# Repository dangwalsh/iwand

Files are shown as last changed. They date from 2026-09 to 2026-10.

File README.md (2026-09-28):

# iWand

iWand is a hand-held device that identifies the color of an object it's pointed at. Point it at something, press the button, and it announces the color out loud.

## Repo layout

- [`firmware/`](firmware/README.md) — embedded code for the Seeed XIAO ESP32S3, using a GY-33 color sensor and a DFPlayer Mini + speaker for audio announcement
- [`electrical/`](electrical/README.md) — KiCad project: schematic, routed 75.9 × 22 mm two-layer PCB, project footprint library (`iwand.pretty`), 3D models, and ready-to-order Gerbers (`fab/iwand-gerbers.zip`)
- [`mechanical/`](mechanical/README.md) — enclosure design in Onshape, with a STEP model of the populated PCB (`iwand-pcb.step`) exported from KiCad

Each directory's README has setup/dependency details specific to that part of the project; `firmware/CLAUDE.md` has the full architecture writeup (wake/sleep flow, pin assignments, library APIs).

## Status

- **Firmware:** a single-file sketch. It runs on hardware with calibration and spoken prompts. The battery-voltage monitor (D10) isn't read yet.
- **Electrical:** the PCB is routed and passes KiCad's design rules and schematic parity checks, with Gerbers ready to order. It hasn't been built or tested yet.
- **Mechanical:** enclosure design in Onshape has just started, from the exported PCB model. The layout along the wand, the component sizes and the required openings are in `mechanical/README.md`.

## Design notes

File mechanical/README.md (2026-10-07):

# iWand — Mechanical

iWand is a hand-held device that identifies the color of an object it's pointed at. This directory holds the mechanical/enclosure design; sibling directories at the repo root hold the corresponding work for the same product — `firmware/` (embedded code) and `electrical/` (KiCad schematic, `iwand.kicad_pro`/`.kicad_sch`, title block "iWand").

The enclosure is designed in Onshape. This directory holds:

- `iwand-pcb.step`: a STEP model of the populated PCB exported from KiCad, which is the reference the enclosure is built around.
- `iWand - Enclosure Top.step`, `iWand - Enclosure Middle.step`, `iWand - Enclosure Rear.step`: the three parts of the enclosure, exported from Onshape. The Onshape document is the source of truth, so re-export these files after design changes.

## Dependencies

- **Onshape** (browser-based) for the enclosure design.
- **KiCad 10** (`kicad-cli`) to re-export `iwand-pcb.step` after the board changes.

## PCB model

`iwand-pcb.step` is the board plus every part that has a 3D model, in millimetres. To re-export it after changing `electrical/iwand.kicad_pcb`, run this from the repo root:

```
"C:\Program Files\KiCad\10.0\bin\kicad-cli.exe" pcb export step --subst-models --force -o mechanical/iwand-pcb.step electrical/iwand.kicad_pcb
```

The XIAO and DFPlayer models come from `electrical/3dmodels/`, and the rest come from KiCad's standard library.

To use it in Onshape, import the file (Import, or drag it onto the Documents page), then insert the resulting Part Studio into an Assembly with the enclosure. After a re-export, use "Update" on the imported part to pick up the new version.

The model leaves out:

- **Q1/Q2:** the `AO3400_SOT23_Adapter` footprint has no 3D model. Allow about 7.6 x 10 mm lying flat on their pins.
- **All off-board parts:** the GY-33, speaker, SW1, LiPo and the JST plugs and cables. Model these in Onshape from the sizes below.

## Components to accommodate

Per the electrical schematic (source of truth: `electrical/iwand.kicad_sch`):

On the main PCB:

- **U1:** Seeed XIAO ESP32S3 (MCU), 21 x 17.8 mm, in female header sockets. Its USB-C port must stay reachable for charging and flashing.
- **U3:** DFPlayer Mini (audio playback), 20.3 x 20.3 mm, in female header sockets. Its microSD slot opens toward the front of the wand, right beside J1, so there's no finger room to swap the card in place. Pull the DFPlayer out of its sockets to change the audio files.
- **Q1/Q2:** AO3400 MOSFETs on SOT-23 adapter boards (~7.6 x 10 mm), mounted flat on their pins. **R1–R4:** through-hole resistors, mounted upright.
- **J1–J4:** JST-PH side-entry sockets, which need room for the plugs and cable bends.
- **SW2:** a right-angle slide switch (power). Its lever sticks out about 4 mm past the same long edge as the USB-C, about 13 mm forward of it, so one side opening or two small cut-outs can serve both.

The board is 75.9 x 22 mm. Its tallest point is the top of the XIAO, about 10–11 mm above the board (3.8 mm low-profile socket + 2.5 mm pin spacer + the module). Pin tails stick out up to about 3 mm below. The XIAO's USB-C port sits over one long edge of the board and must line up with a slot in the enclosure wall.

**Charging:** the battery stays in and charges over USB-C, but only with SW2 switched on. The XIAO's small charge LED sits on top of the module, right beside the USB-C port. Leave a window or light pipe above it, or make the USB slot wide enough to show the glow.

Off-board, on JST-PH cables:

- **GY-33 color sensor (J1):** 24.3 x 26.7 mm, with four corner screw holes about 21 x 19.7 mm apart (measured from a photo, to be confirmed with calipers). The sensor and LEDs face forward, so it needs an aperture at the pointing end of the wand. Allow about 20 mm behind it for the cable.
- **Speaker (J2):** 8 Ω, 28 mm round, ~5 mm deep. It needs a grille, ideally with a closed back volume.
- **Wake button SW1 (J3):** a panel-mount momentary pushbutton, reachable as the wand's trigger.
- **LiPo (J4):** 3.7 V, with a compartment. It stays connected and charges in place, so it only needs access for replacement.

The widest parts are the speaker (28 mm) and the GY-33's face, which together set the enclosure's minimum cross-section.

## Layout along the wand

From rear to front: **speaker (rear end cap) → battery → PCB → GY-33 (tip)**.

- The battery, speaker and button plugs (J4, J2, J3) face the rear, toward the battery and speaker, which keeps their leads short. The plug housings stick out about 7 mm behind the board, so leave that gap, plus room for the cables to bend, before the battery.
- The battery sits on the wand's centre line, so the weight stays centred. Any cell that fits the tube's inside diameter will do. It doesn't need to fit under the board.
- J1 faces forward. The GY-33 cable runs from it to the sensor at the tip, and needs about 20 mm behind the sensor.

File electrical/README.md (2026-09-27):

# iWand Electrical

KiCad schematic for the iWand color-identifying wand (Seeed XIAO ESP32S3 + GY-33 color sensor + DFPlayer Mini + AO3400 power gating). See `firmware/CLAUDE.md` for how the pin assignments here map to the firmware.

## Dependencies

- **KiCad 7.0 or newer** (developed with KiCad 10). The schematic (`iwand.kicad_sch`) is in the KiCad 7 s-expression format (`version 20230121`). Older KiCad versions won't open it.

The module symbols (`wand_parts:XIAO_ESP32S3`, `wand_parts:DFPlayer_Mini`) are embedded directly in `iwand.kicad_sch`, so there's no external symbol library to install. ERC warns that the `wand_parts` library isn't configured and that `Device:Q_NMOS_GDS` is missing from KiCad's current `Device` library. Both warnings are harmless, because the embedded copies are used.

## Footprints

Project footprints live in `iwand.pretty`, registered through the project's `fp-lib-table` as `iwand`:

| Footprint | Used by | Source |
|---|---|---|
| `XIAO_ESP32S3_Socket` | U1 | Pad positions from Seeed's `XIAO-ESP32-S3-DIP`, without its castellated SMD pads. USB-C is at +X; B+/B- on the fab layer mark the underside battery pads. |
| `DFPlayer_Mini_Socket` | U3 | DFR0299 datasheet drawing: 20.32 mm square, 2 x 8 pins, rows 18.034 mm apart. |
| `AO3400_SOT23_Adapter` | Q1, Q2 | 1 x 3 pins in the adapter board's S-D-G order (adapter labels 2-3-1). Pads are numbered for `Q_NMOS_GDS`. The adapter outline (~7.6 x 10 mm) is estimated from a photo. |

Everything else is stock KiCad:
- DIN0207 through-hole resistors, lying flat
- a 3 mm disc capacitor
- a C&K OS102011MA1QN1-style right-angle slide switch
- JST-PH side-entry sockets (J1-J4)
- a 1 x 2 pin header (J5)

## Board

The board is 75.9 x 22 mm, laid out as a "spine" along the wand. From the rear:
- J4 battery, J2 speaker and J3 button plugs, facing the rear
- the XIAO, with USB-C over the lower long edge; R1-R6 lie flat underneath it
- Q1/Q2 with J5, SW2 and C1
- the DFPlayer
- J1, facing forward to the GY-33

The module sockets are 3M 929870 low-profile strips, 3.8 mm tall, bought as 10-pin strips and cut to length. In them, the XIAO sits about 6.3 mm up (3.8 mm socket + 2.5 mm pin spacer). Its courtyard therefore covers only its socket strips and USB plug, so parts up to about 5 mm tall can go underneath.

For the 3D view:
- **Sockets:** 3M's STEP model is a 10-pin strip, so the view uses KiCad's 1x7/1x8 socket models scaled to 3.8 mm instead.
- **XIAO:** Seeed's STEP file (in `3dmodels/`), drawn 6.3 mm up. The pin spacer under it isn't modelled.
- **DFPlayer:** DFRobot's DFR0299 STEP file (in `3dmodels/`, drawn in inches, Y-up). It includes the module's own pin header, with its spacer resting on the socket top. Its microSD slot opens toward the front of the board, facing J1.

Do a dry fit before soldering. A standard 6 mm male pin may bottom out in a 3.8 mm socket and ride slightly higher than 6.3 mm.

## Mounting and off-board parts

- U1 and U3 plug into female header sockets so they stay removable. Q1/Q2 are AO3400s already soldered to SOT-23 adapter boards, which are mounted flat on their pins.
- The GY-33, speaker, wake button and battery sit off the board on JST-PH connectors:
  - **J1 (GY-33):** a 4-wire pigtail soldered into the sensor's GND/DR/CT/VCC holes, in that order.
  - **J2:** speaker.
  - **J3:** wake button.
  - **J4:** LiPo.
- JST battery polarity isn't standardised. Check each battery against the board's + mark before plugging it in.
- The XIAO's battery pads are on its underside, not on its headers. **J5** takes two short wires from those BAT+/BAT- pads so the XIAO can run from, and charge, the battery on J4.

## Power and charging

- The battery stays in the wand and charges through the XIAO's USB-C (about 100 mA).
- **SW2** is the power switch, in the battery + lead (J4 → SW2 → VBAT). Off disconnects everything, including the charger, so the battery only charges with SW2 on.
- The XIAO's charge LED sits next to its USB-C port, so the enclosure needs a window or light pipe there.
- **R5/R6** (1M each) divide VBAT by 2 into D10, which is an ADC input. **C1** (100 nF) steadies the reading. The divider draws about 2 µA, and nothing when SW2 is off.

## Routing and fabrication

- **Stack-up:** 2 layers, 1.6 mm. Rules: 0.2 mm clearance, 0.5 mm copper to edge. Every connection is routed. DRC and the schematic parity check pass with no errors.
- **Net classes:**
  - **Default:** 0.25 mm tracks, 0.6/0.3 mm vias.
  - **Power:** 0.5 mm tracks, 0.8/0.4 mm vias. Covers `VBAT`, `BAT_IN`, `GND`, `SPK1`/`SPK2`, `AUDIO_GND` and `SENSOR_GND`. Branches to R5/R6/C1 and the gate resistors use 0.25 mm, since they carry almost no current.
- **Module socket pads:** 1.6 mm, so a 0.25 mm track can pass between two 2.54 mm-pitch pins.
- **Ground:** GND pours on both layers, tied together by stitching vias.
- **Fab files:** `fab/iwand-gerbers.zip` (copper, mask, silkscreen, edge cuts, and plated and non-plated drill files). Regenerate it with KiCad's Fabrication Outputs, or with `kicad-cli pcb export gerbers` / `export drill`, after any board change.

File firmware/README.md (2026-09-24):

# iWand Firmware

Firmware for the iWand color-identifying wand (Seeed XIAO ESP32S3 + GY-33 color sensor + DFPlayer Mini). See `CLAUDE.md` for architecture and pin assignment details.

## Dependencies

Install via the Arduino IDE Library Manager:

- **GY33_Colour_Sensor** — driver for the GY-33 color sensor (TCS34725-based), used over I2C. Source: https://github.com/You-010/GY33_Arduino
- **DFRobotDFPlayerMini** — driver for the DFPlayer Mini MP3 module, used over UART. Source: https://github.com/DFRobot/DFRobotDFPlayerMini

Board support: install the **esp32** board package (Espressif Systems) via Boards Manager, and select an ESP32S3 board profile (e.g. "XIAO_ESP32S3" if available, otherwise a generic "ESP32S3 Dev Module").

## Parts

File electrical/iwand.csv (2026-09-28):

Reference | Qty | Value | DNP | Exclude from BOM | Exclude from Board | Exclude from Simulation | Exclude from Position Files | Footprint | Datasheet
C1 | 1 | 100n |  |  |  |  | ${EXCLUDE_FROM_POS_FILES} | Capacitor_THT:C_Disc_D3.0mm_W1.6mm_P2.50mm
J1 | 1 | GY-33 (GND DR CT VCC) |  |  |  |  | ${EXCLUDE_FROM_POS_FILES} | Connector_JST:JST_PH_S4B-PH-K_1x04_P2.00mm_Horizontal
J2 | 1 | Speaker 8R |  |  |  |  | ${EXCLUDE_FROM_POS_FILES} | Connector_JST:JST_PH_S2B-PH-K_1x02_P2.00mm_Horizontal
J3 | 1 | Wake button SW1 |  |  |  |  | ${EXCLUDE_FROM_POS_FILES} | Connector_JST:JST_PH_S2B-PH-K_1x02_P2.00mm_Horizontal
J4 | 1 | LiPo 3.7V (+ -) |  |  |  |  | ${EXCLUDE_FROM_POS_FILES} | Connector_JST:JST_PH_S2B-PH-K_1x02_P2.00mm_Horizontal
J5 | 1 | XIAO BAT+ BAT- link |  |  |  |  | ${EXCLUDE_FROM_POS_FILES} | Connector_PinHeader_2.54mm:PinHeader_1x02_P2.54mm_Vertical
Q1,Q2 | 2 | AO3400 |  |  |  |  | ${EXCLUDE_FROM_POS_FILES} | iwand:AO3400_SOT23_Adapter
R1,R3 | 2 | 100 |  |  |  |  | ${EXCLUDE_FROM_POS_FILES} | Resistor_THT:R_Axial_DIN0207_L6.3mm_D2.5mm_P7.62mm_Horizontal
R2,R4 | 2 | 10k |  |  |  |  | ${EXCLUDE_FROM_POS_FILES} | Resistor_THT:R_Axial_DIN0207_L6.3mm_D2.5mm_P7.62mm_Horizontal
R5,R6 | 2 | 1M |  |  |  |  | ${EXCLUDE_FROM_POS_FILES} | Resistor_THT:R_Axial_DIN0207_L6.3mm_D2.5mm_P7.62mm_Horizontal
SW2 | 1 | Power |  |  |  |  | ${EXCLUDE_FROM_POS_FILES} | Button_Switch_THT:SW_Slide_SPDT_Angled_CK_OS102011MA1Q
U1 | 1 | XIAO ESP32-S3 |  |  |  |  | ${EXCLUDE_FROM_POS_FILES} | iwand:XIAO_ESP32S3_Socket
U3 | 1 | DFPlayer Mini |  |  |  |  | ${EXCLUDE_FROM_POS_FILES} | iwand:DFPlayer_Mini_Socket

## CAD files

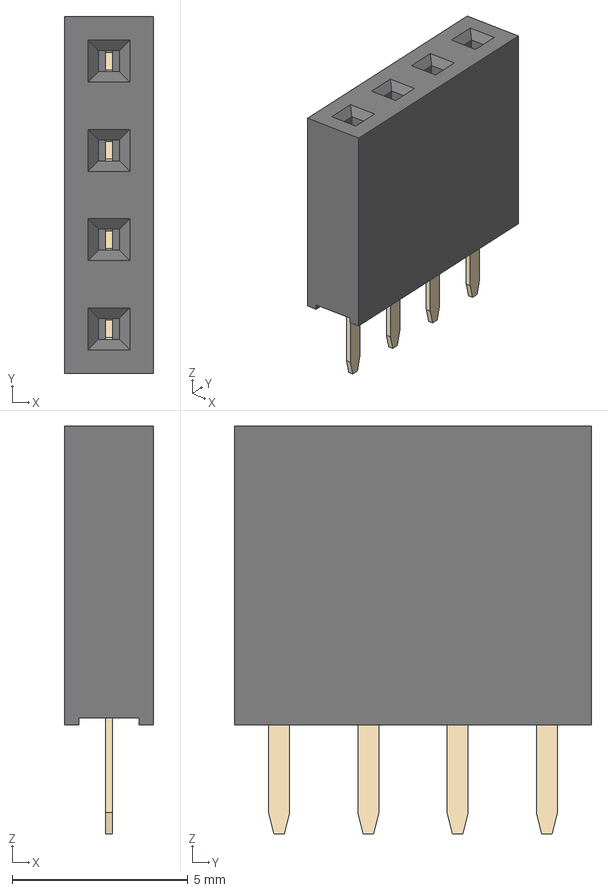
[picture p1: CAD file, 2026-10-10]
electrical/3dmodels/PinSocket_1x04_P2.54mm_Vertical.step
2.54 x 10.2 x 11.6 mm

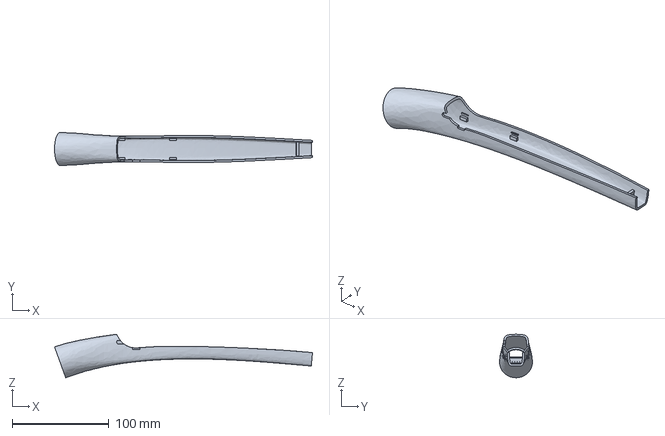
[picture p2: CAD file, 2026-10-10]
mechanical/iWand - Enclosure Middle.step
267.0 x 34.0 x 45.1 mm

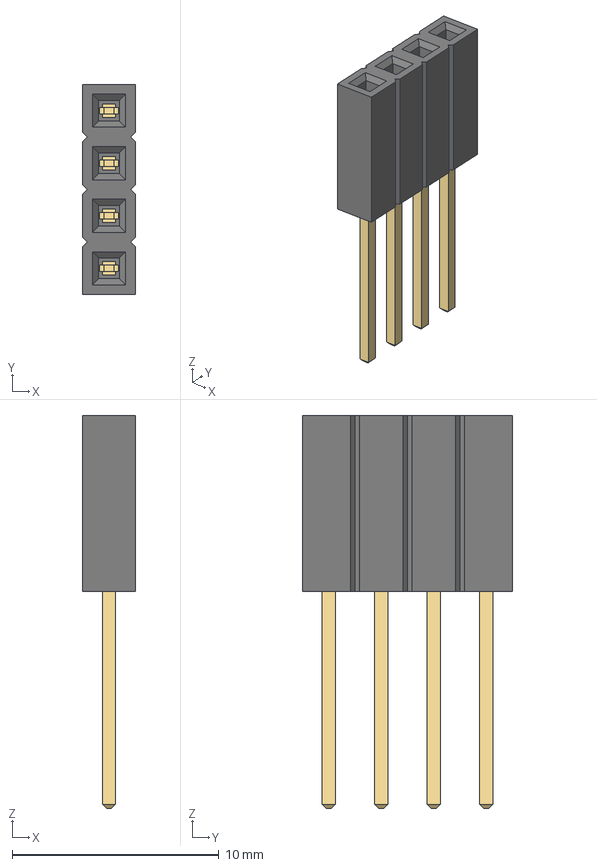
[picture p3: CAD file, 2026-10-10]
electrical/3dmodels/PinSocket_1x04_P2.54mm_Vertical_Stacking.step
2.54 x 10.2 x 19.0 mm
pins

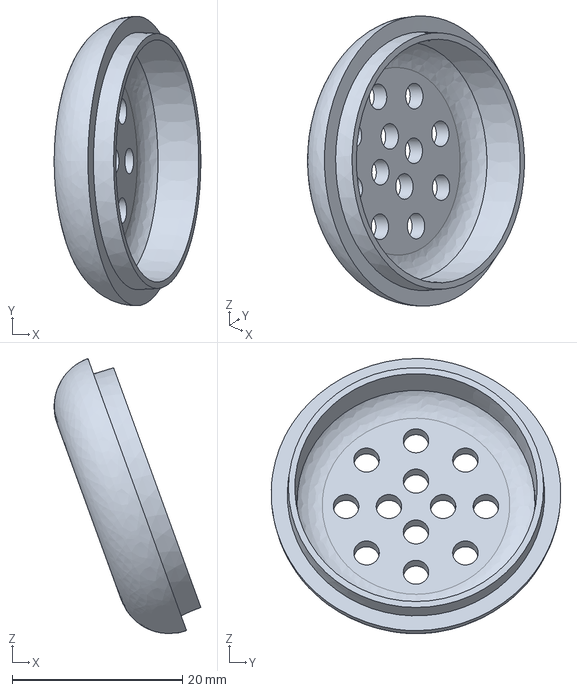
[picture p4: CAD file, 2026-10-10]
mechanical/iWand - Enclosure Rear.step
17.3 x 34.0 x 32.3 mm

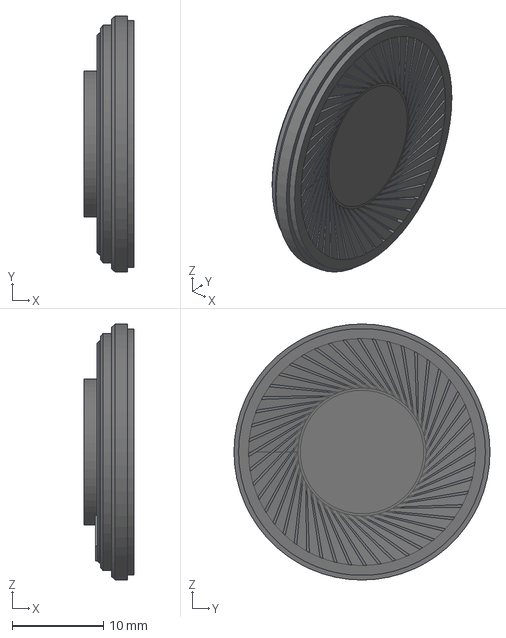
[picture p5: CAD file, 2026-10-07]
electrical/3dmodels/28mm 2W 8 Ohm Speaker.step
5.50 x 28.0 x 28.0 mm

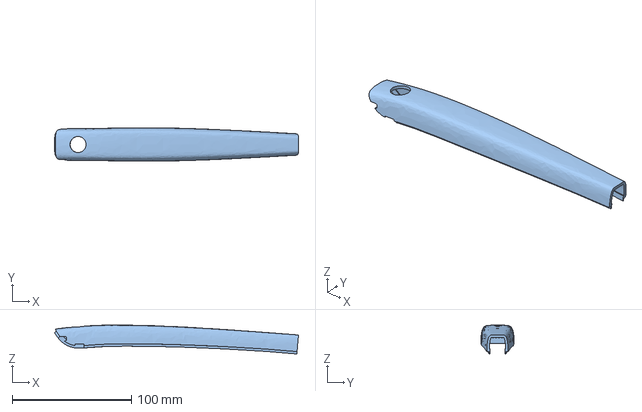
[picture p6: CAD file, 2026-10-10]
mechanical/iWand - Enclosure Top.step
204.6 x 28.1 x 24.3 mm

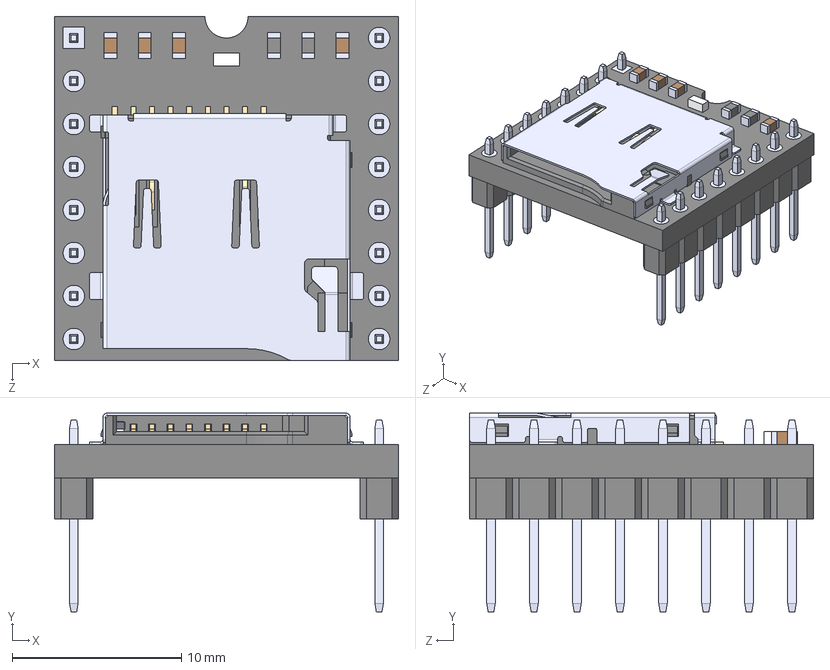
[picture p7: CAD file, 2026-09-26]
electrical/3dmodels/DFPlayer_Mini.step
20.3 x 11.8 x 20.3 mm

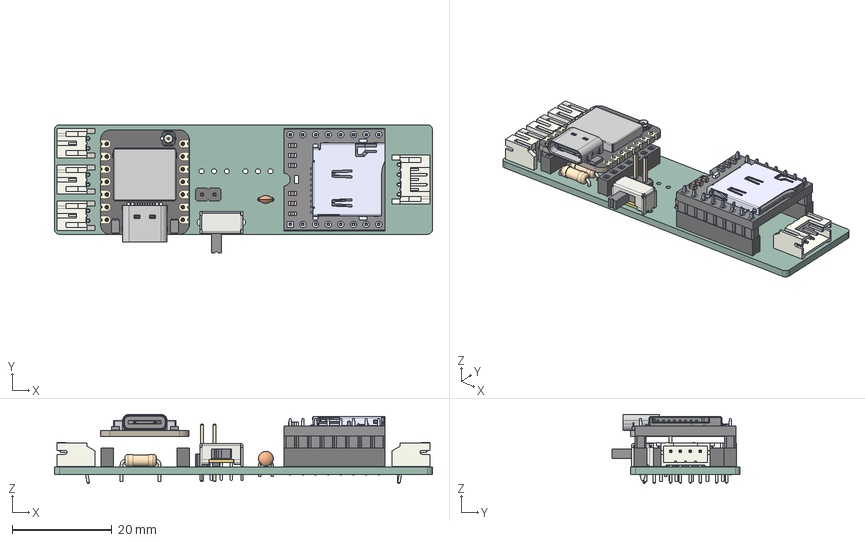
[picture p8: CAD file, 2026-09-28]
mechanical/iwand-pcb.step
75.9 x 25.8 x 13.9 mm
JST_S2B_PH_K x 3
R_Axial_DIN0207_L63mm_D25mm_P762mm_Horizontal x 6
SW_Slide_SPDT_Angled_CK_OS102011MA1Q
JST_S4B_PH_K
PinSocket_1x08_P2.54mm_Vertical x 2
DFR0299
PinHeader_1x02_P254mm_Vertical
C_Disc_D30mm_W16mm_P250mm
PinSocket_1x07_P2.54mm_Vertical x 2
BOSS-EXTRUDE14_8_
BOSS-EXTRUDE7_4_
BOSS-EXTRUDE7_3_
BOSS-EXTRUDE14_4_
BOSS-EXTRUDE14_2_
BOSS-EXTRUDE14_11_
BOSS-EXTRUDE7_7_
BOSS-EXTRUDE14_9_
BOSS-EXTRUDE14_3_
BOSS-EXTRUDE14_7_
MIRROR2
BOSS-EXTRUDE14_5_
BOSS-EXTRUDE14_12_
BOSS-EXTRUDE7_8_
BOSS-EXTRUDE7_1_
BOSS-EXTRUDE14_10_
BOSS-EXTRUDE7_9_
BOSS-EXTRUDE14_6_
BOSS-EXTRUDE14_1_
BOSS-EXTRUDE7_6_
BOSS-EXTRUDE7_2_
CUT-EXTRUDE5
BOSS-EXTRUDE7_5_
Shield
Pins x 2
U.FL-R-SMT-1_10_ v1
iwand_PCB

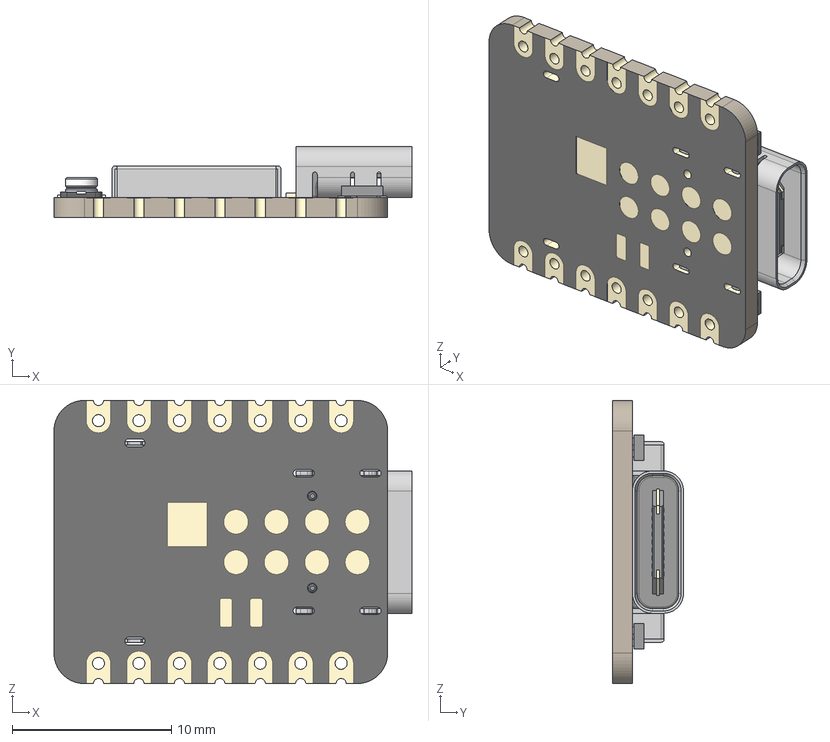
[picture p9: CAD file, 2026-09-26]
electrical/3dmodels/XIAO-ESP32S3.step
22.5 x 4.46 x 17.8 mm
BOSS-EXTRUDE14_8_
BOSS-EXTRUDE7_4_
BOSS-EXTRUDE7_3_
BOSS-EXTRUDE14_4_
BOSS-EXTRUDE14_2_
BOSS-EXTRUDE14_11_
BOSS-EXTRUDE7_7_
BOSS-EXTRUDE14_9_
BOSS-EXTRUDE14_3_
BOSS-EXTRUDE14_7_
MIRROR2
BOSS-EXTRUDE14_5_
BOSS-EXTRUDE14_12_
BOSS-EXTRUDE7_8_
BOSS-EXTRUDE7_1_
BOSS-EXTRUDE14_10_
BOSS-EXTRUDE7_9_
BOSS-EXTRUDE14_6_
BOSS-EXTRUDE14_1_
BOSS-EXTRUDE7_6_
BOSS-EXTRUDE7_2_
CUT-EXTRUDE5
BOSS-EXTRUDE7_5_
Shield
Pins x 2
U.FL-R-SMT-1_10_ v1

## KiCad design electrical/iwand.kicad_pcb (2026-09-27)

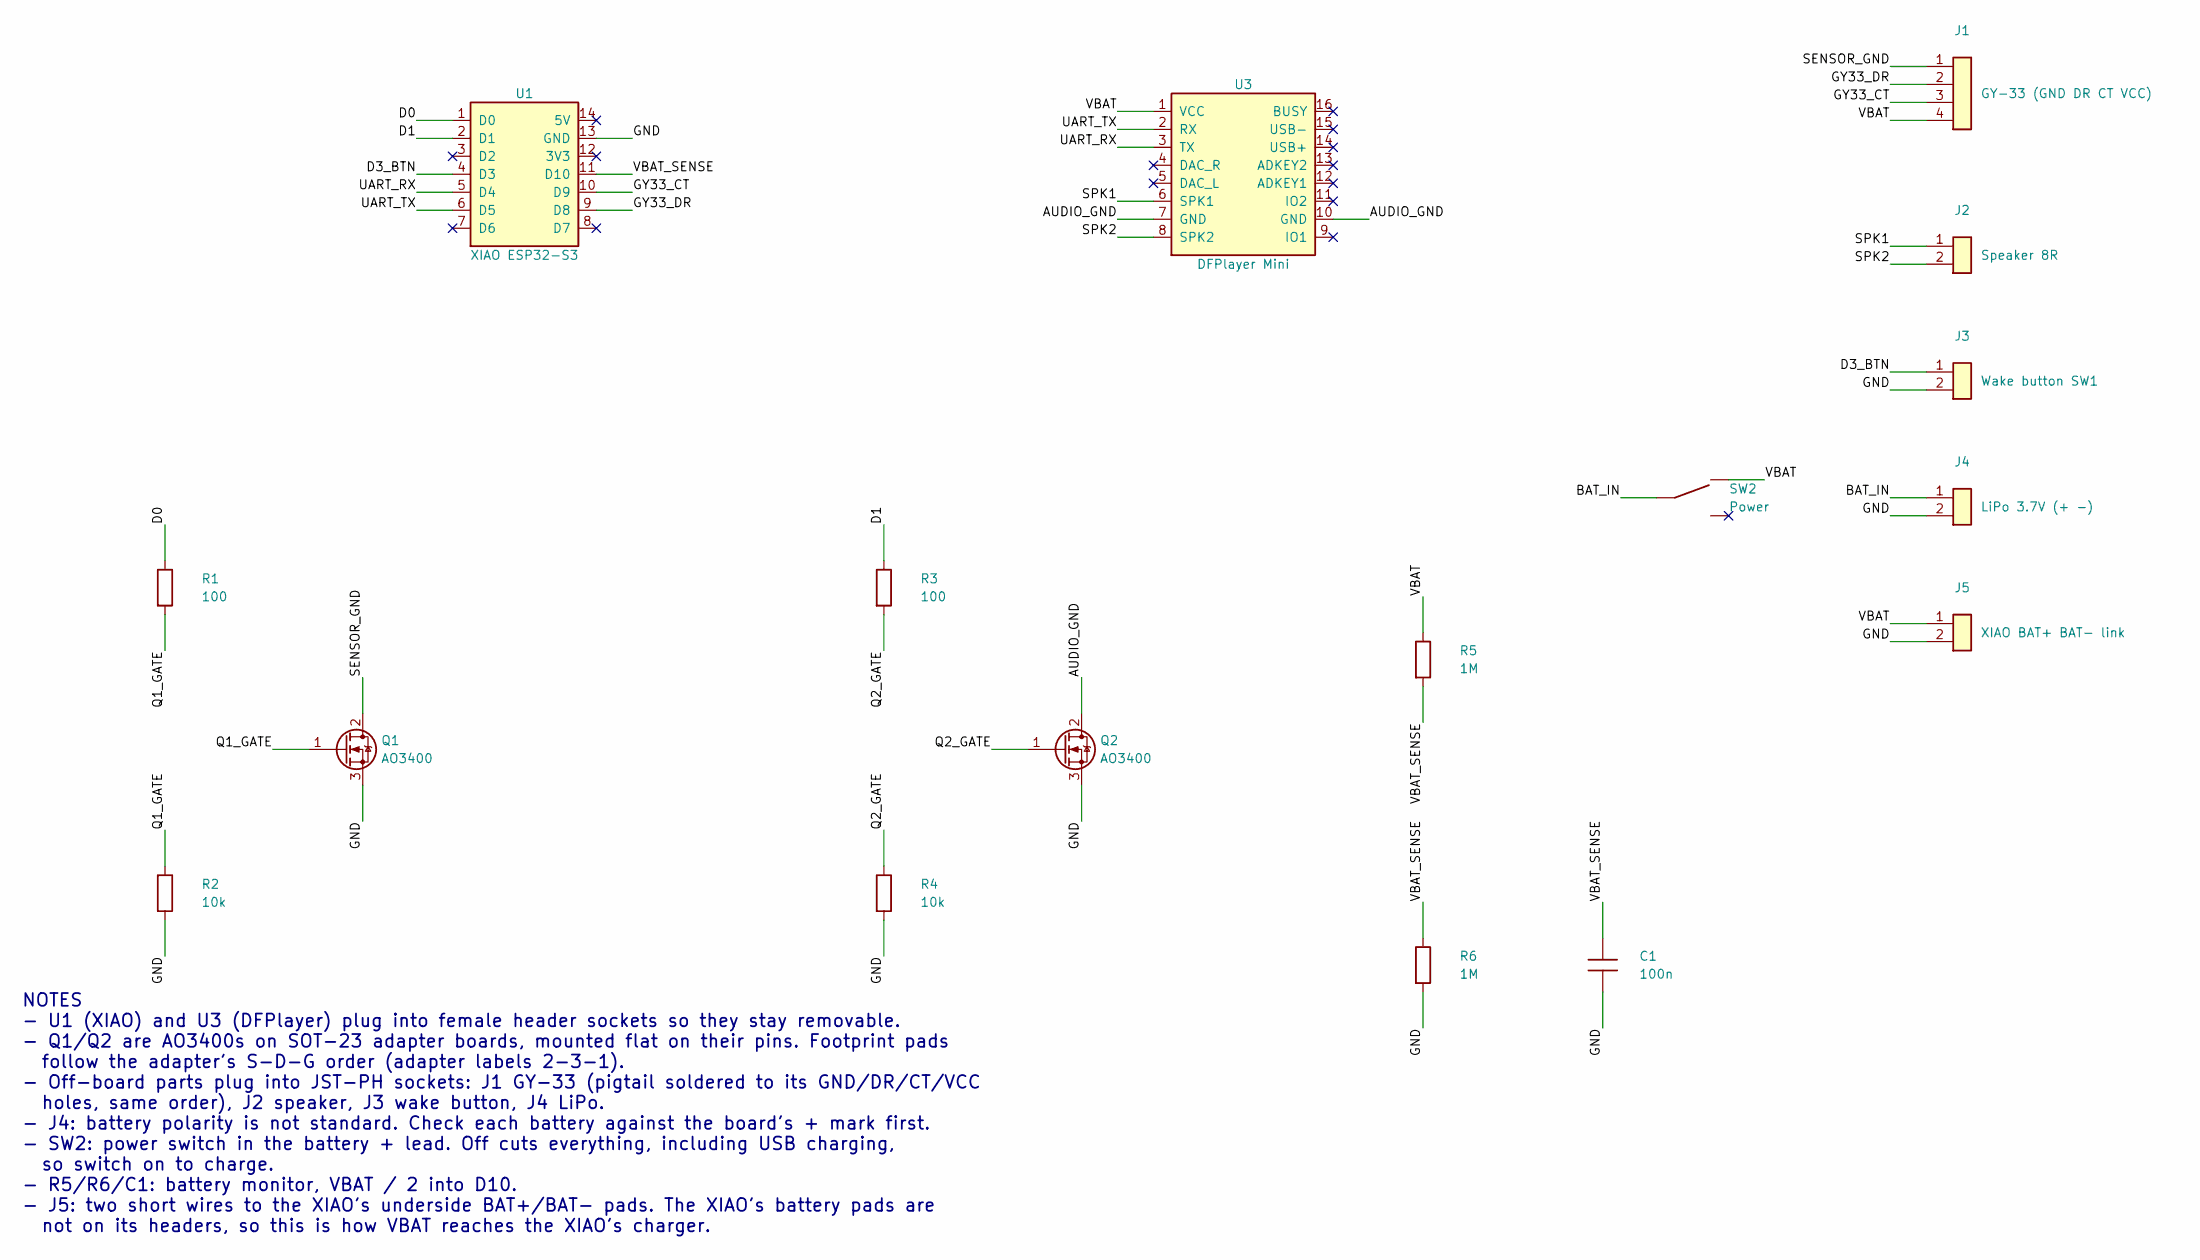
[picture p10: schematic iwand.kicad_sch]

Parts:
C1: 100n; C_Disc_D3.0mm_W1.6mm_P2.50mm
J1: GY-33 (GND DR CT VCC); JST_PH_S4B-PH-K_1x04_P2.00mm_Horizontal
J2: Speaker 8R; JST_PH_S2B-PH-K_1x02_P2.00mm_Horizontal
J3: Wake button SW1; JST_PH_S2B-PH-K_1x02_P2.00mm_Horizontal
J4: LiPo 3.7V (+ -); JST_PH_S2B-PH-K_1x02_P2.00mm_Horizontal
J5: XIAO BAT+ BAT- link; PinHeader_1x02_P2.54mm_Vertical
Q1, Q2: AO3400; AO3400_SOT23_Adapter
R1, R3: 100; R_Axial_DIN0207_L6.3mm_D2.5mm_P7.62mm_Horizontal
R2, R4: 10k; R_Axial_DIN0207_L6.3mm_D2.5mm_P7.62mm_Horizontal
R5, R6: 1M; R_Axial_DIN0207_L6.3mm_D2.5mm_P7.62mm_Horizontal
SW2: Power; SW_Slide_SPDT_Angled_CK_OS102011MA1Q
U1: XIAO ESP32-S3; XIAO_ESP32S3_Socket
U3: DFPlayer Mini; DFPlayer_Mini_Socket

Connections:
/AUDIO_GND: Q2.2 (D), U3.7 (GND), U3.10 (GND)
/BAT_IN: J4.1, SW2.2 (B)
/D0: R1.1, U1.1 (D0)
/D1: R3.1, U1.2 (D1)
/D3_BTN: J3.1, U1.4 (D3)
/GND: C1.2, J3.2, J4.2, J5.2, Q1.3 (S), Q2.3 (S), R2.2, R4.2, R6.2, U1.13 (GND)
/GY33_CT: J1.3, U1.10 (D9)
/GY33_DR: J1.2, U1.9 (D8)
/Q1_GATE: Q1.1 (G), R1.2, R2.1
/Q2_GATE: Q2.1 (G), R3.2, R4.1
/SENSOR_GND: J1.1, Q1.2 (D)
/SPK1: J2.1, U3.6 (SPK1)
/SPK2: J2.2, U3.8 (SPK2)
/UART_RX: U1.5 (D4), U3.3 (TX)
/UART_TX: U1.6 (D5), U3.2 (RX)
/VBAT: J1.4, J5.1, R5.1, SW2.1 (A), U3.1 (VCC)
/VBAT_SENSE: C1.1, R5.2, R6.1, U1.11 (D10)

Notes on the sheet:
NOTES - U1 (XIAO) and U3 (DFPlayer) plug into female header sockets so they stay removable. - Q1/Q2 are AO3400s on SOT-23 adapter boards, mounted flat on their pins. Footprint pads follow the adapter's S-D-G order (adapter labels 2-3-1). - Off-board parts plug into JST-PH sockets: J1 GY-33 (pigtail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

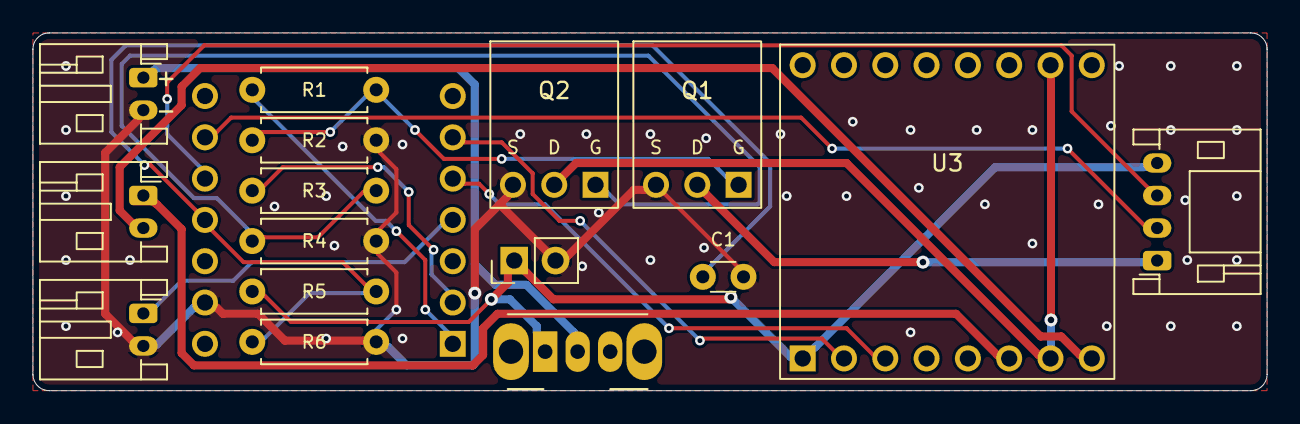
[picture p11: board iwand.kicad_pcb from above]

Board: 2 copper layers, 75.9 x 22.0 mm, 17 parts (0 on the bottom side), 17 nets.

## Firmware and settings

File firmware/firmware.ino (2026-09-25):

#include <Wire.h>                  // not used directly; GY33.h depends on it
#include <GY33.h>                  // https://github.com/You-010/GY33_Arduino
#include <DFRobotDFPlayerMini.h>   // DFRobot DFPlayer Mini MP3 module
#include <esp_sleep.h>
#include <driver/rtc_io.h>         // RTC-domain pull-up for the wake pin during deep sleep
#include <Preferences.h>           // ESP32 NVS -- persists the black offset across deep sleep

// ---------------------------------------------------------------------------
// Pin assignments -- from the schematic, board is a Seeed XIAO ESP32S3.
// Silkscreen D-labels translated to GPIO numbers per Seeed's pinout:
//   D0=GPIO1  D1=GPIO2  D3=GPIO4  D4=GPIO5  D5=GPIO6  D8=GPIO7  D9=GPIO8
// Sensor MOSFET gate moved from D2 (GPIO3, an ESP32-S3 strapping pin) to
// D0 (GPIO1), a plain unused pin with no competing native function -- update
// the schematic's R1 net from D2 to D0 to match.
// D4/D5 UART roles match the schematic's crossover wiring (D4 = MCU RX, fed
// by DFPlayer TX; D5 = MCU TX, feeding DFPlayer RX).
// D8/D9 are wired to the GY-33's DR/CT pins, which are SDA/SCL in I2C mode
// and RX/TX in serial mode. The sensor runs in serial mode (its factory
// default), so D8 = MCU TX -> GY-33 DR (RX), D9 = MCU RX <- GY-33 CT (TX).
// Grouped for tidiness: D0/D1 = MOSFET gates, D3 = wake button, D4/D5 =
// DFPlayer UART, D8/D9 = GY-33 UART.
// ---------------------------------------------------------------------------
#define SENSOR_MOSFET_PIN  1   // D0: R1 -> Q1 gate, switches GY-33 power
#define PLAYER_MOSFET_PIN  2   // D1: R3 -> Q2 gate, switches DFPlayer power
#define WAKE_BUTTON_PIN    4   // D3: SW1 to GND; wakes MCU via ext0 (active LOW)
#define DFPLAYER_RX_PIN    5   // D4: ESP32 RX <- DFPlayer TXD
#define DFPLAYER_TX_PIN    6   // D5: ESP32 TX -> DFPlayer RXD
#define SENSOR_TX_PIN      7   // D8: ESP32 TX -> GY-33 DR (RX)
#define SENSOR_RX_PIN      8   // D9: ESP32 RX <- GY-33 CT (TX)

// Assumes each AO3400 is wired as a low-side switch (drain to the device's
// ground return, source to system ground): gate HIGH turns the device ON.
// Invert these if the hardware ends up wired the other way.
#define MOSFET_ON  HIGH
#define MOSFET_OFF LOW

#define SENSOR_WARMUP_MS  300   // GY-33 settle time after power-up -- untested guess, tune later
#define SENSOR_BAUD       9600  // GY-33 factory-default serial baud rate
#define PLAYER_WARMUP_MS  2000  // DFPlayer Mini needs time to mount its SD card before it'll respond
#define PLAYER_VOLUME     20    // 0-30
#define READ_TIMEOUT_MS   1000
// In serial mode the GY-33 streams one frame per output type (raw, LCC,
// processed -- all enabled by begin()) and update() returns true for each.
// Waiting for this many frames ensures every field has fresh data.
#define FRAMES_PER_READING 3
// Colour classification thresholds, on channels normalised so the calibrated
// black point is 0 and the white point is 1, then gamma-encoded to match how
// bright things look (see classifyColour()) -- tune on real targets using the
// "Normalised" debug line.
#define DISPLAY_GAMMA        2.2f   // standard sRGB-like perceptual curve
#define BLACK_MAX_VALUE      0.25f  // brightest channel below this -> Black
#define WHITE_MIN_VALUE      0.80f  // unsaturated and at least this bright -> White, else Gray
#define WHITE_MAX_SATURATION 0.15f  // channels this close together -> White/Gray/Black
#define PLAY_TIMEOUT_MS   5000
// Spoken calibration prompts, in the SD card's /mp3 folder.
#define TRACK_CAL_WHITE   11    // 0011.mp3: "point at white and press the button"
#define TRACK_CAL_BLACK   12    // 0012.mp3: "point at black and press the button"
#define TRACK_CAL_DONE    13    // 0013.mp3: "calibration complete"
#define CAL_STEP_TIMEOUT_MS 30000 // abort calibration if SW1 isn't pressed in time, to save battery
#define CAL_SETTLE_MS     500     // time for the GY-33 to finish white balance -- untested guess
#define DEBOUNCE_MS       30
// Debug aid: the XIAO's USB serial drops during deep sleep and the host takes
// a moment to reconnect after each wake, so early prints are lost. Wait up to
// this long for the serial monitor at boot. Set to 0 for battery use.
#define SERIAL_WAIT_MS    3000

HardwareSerial sensorSerial(2);
GY33_UART sensor(sensorSerial);
HardwareSerial dfSerial(1);
DFRobotDFPlayerMini player;
bool playerReady = false;
Preferences prefs;

// Raw reading of the white calibration target, loaded from NVS at boot.
GY33_Raw whitePoint = {0, 0, 0, 0};
bool haveWhitePoint = false;

// Maps a classifyColour() name to a track number on the DFPlayer's SD card.
// Track files live in the card's /mp3 folder as 0001.mp3, 0002.mp3, etc.
// (see playTrack()).
int trackForColour(const char* colour) {
  if (strcmp(colour, "Black") == 0)  return 1;
  if (strcmp(colour, "White") == 0)  return 2;
  if (strcmp(colour, "Gray") == 0)   return 3;
  if (strcmp(colour, "Red") == 0)    return 4;
  if (strcmp(colour, "Orange") == 0) return 5;
  if (strcmp(colour, "Yellow") == 0) return 6;
  if (strcmp(colour, "Green") == 0)  return 7;
  if (strcmp(colour, "Cyan") == 0)   return 8;
  if (strcmp(colour, "Blue") == 0)   return 9;
  if (strcmp(colour, "Purple") == 0) return 10;
  return 0; // unrecognised -- don't play anything
}

void powerSensorOn() {
  digitalWrite(SENSOR_MOSFET_PIN, MOSFET_ON);
  delay(SENSOR_WARMUP_MS);
}

void powerSensorOff() {
  digitalWrite(SENSOR_MOSFET_PIN, MOSFET_OFF);
}

void powerPlayerOn() {
  digitalWrite(PLAYER_MOSFET_PIN, MOSFET_ON);
  delay(PLAYER_WARMUP_MS);
}

void powerPlayerOff() {
  digitalWrite(PLAYER_MOSFET_PIN, MOSFET_OFF);
}

void startSensor() {
  powerSensorOn();
  sensorSerial.begin(SENSOR_BAUD, SERIAL_8N1, SENSOR_RX_PIN, SENSOR_TX_PIN);
  sensor.begin(); // enables streaming of raw, LCC and processed frames
}

void stopSensor() {
  // Release the TX pin before cutting the sensor's ground, so the MCU isn't
  // driving a signal into an unpowered module.
  sensorSerial.end();
  powerSensorOff();
}

// Reads frames until every output type has refreshed. Returns false on timeout.
bool refreshSensor() {
  int frames = 0;
  unsigned long start = millis();
  while (millis() - start < READ_TIMEOUT_MS) {
    if (sensor.update() && ++frames >= FRAMES_PER_READING) return true;
  }
  Serial.printf("Sensor read timed out (%d frames received).\n", frames);
  return false;
}

// Scales a raw channel so the black point reads 0 and the white point reads 1,
// then gamma-encodes it. The sensor is linear in light energy, but perceived
// brightness isn't: a mid-tone paper reflecting ~20% of what white paper does
// reads 0.2 linear yet looks about half as bright (0.2^(1/2.2) ~= 0.48).
float normalise(uint16_t raw, uint16_t black, uint16_t white) {
  float span = (white > black) ? (float)(white - black) : 1.0f;
  float linear = (raw > black) ? (raw - black) / span : 0.0f;
  return powf(fminf(linear, 1.0f), 1.0f / DISPLAY_GAMMA);
}

// Names the colour of a raw reading by its hue, saturation and brightness.
// The library's colour() isn't used: it treats the module's colour byte as an
// index 0-7, but the GY-33 reports it as bit flags (e.g. 8 = white), and its
// palette doesn't match our tracks anyway.
const char* classifyColour(const GY33_Raw& raw) {
  GY33_Raw black = sensor.getBlackOffset();
  // Without a white point, scale by the clear channel instead: hue and
  // saturation still work, but brightness (and so Black) can't be judged.
  GY33_Raw white = haveWhitePoint ? whitePoint : GY33_Raw{raw.c, raw.c, raw.c, raw.c};
  float r = normalise(raw.r, black.r, white.r);
  float g = normalise(raw.g, black.g, white.g);
  float b = normalise(raw.b, black.b, white.b);

  float maxc = fmaxf(r, fmaxf(g, b));
  float minc = fminf(r, fminf(g, b));
  float delta = maxc - minc;
  float sat = (maxc > 0) ? delta / maxc : 0;
  float hue = 0;
  if (delta > 0) {
    if (maxc == r)      hue = 60 * fmodf((g - b) / delta, 6);
    else if (maxc == g) hue = 60 * ((b - r) / delta + 2);
    else                hue = 60 * ((r - g) / delta + 4);
    if (hue < 0) hue += 360;
  }
  Serial.printf("Normalised r=%.2f g=%.2f b=%.2f -> hue=%.0f sat=%.2f val=%.2f%s\n",
                r, g, b, hue, sat, maxc, haveWhitePoint ? "" : " (no white point)");

  if (haveWhitePoint && maxc < BLACK_MAX_VALUE) return "Black";
  if (sat < WHITE_MAX_SATURATION) {
    // Without a white point every channel is scaled to the clear channel, so
    // brightness is meaningless and White can't be told from Gray.
    return (!haveWhitePoint || maxc >= WHITE_MIN_VALUE) ? "White" : "Gray";
  }
  // Hue bands in degrees. Measured (gamma-encoded) so far: teal paper ~166,
  // blue ~207, purple ~250. Others are still rough starting points.
  if (hue < 15 || hue >= 330) return "Red";
  if (hue < 40)  return "Orange";
  if (hue < 70)  return "Yellow";
  if (hue < 150) return "Green";
  if (hue < 200) return "Cyan";
  if (hue < 230) return "Blue";
  return "Purple";
}

// Reads the sensor and returns its colour name, or "Unknown" on timeout.
const char* readColour() {
  if (!refreshSensor()) return "Unknown";
  GY33_Raw raw = sensor.getRaw();
  Serial.printf("Sensor read: raw r=%u g=%u b=%u c=%u\n", raw.r, raw.g, raw.b, raw.c);
  return classifyColour(raw);
}

// Blocks until the DFPlayer reports the current track finished, or times out.
void waitForPlaybackToFinish() {
  unsigned long start = millis();
  while (millis() - start < PLAY_TIMEOUT_MS) {
    if (player.available() && player.readType() == DFPlayerPlayFinished) {
      return;
    }
  }
  Serial.println("Playback timed out.");
}

// Powers the DFPlayer and brings up its UART. Sets playerReady on success.
void startPlayer() {
  powerPlayerOn();
  dfSerial.begin(9600, SERIAL_8N1, DFPLAYER_RX_PIN, DFPLAYER_TX_PIN);
  playerReady = player.begin(dfSerial);
  if (playerReady) {
    player.volume(PLAYER_VOLUME);
  } else {
    Serial.println("DFPlayer init failed.");
  }
}

void stopPlayer() {
  // Release the TX pin before cutting the player's ground, as for the sensor.
  dfSerial.end();
  powerPlayerOff();
  playerReady = false;
}

// Plays /mp3/NNNN.mp3 on the SD card and blocks until it finishes. Does
// nothing if the player failed to start, so callers can carry on without audio.
// playMp3Folder() picks the file by its name; play() would instead use the
// order files were copied onto the card.
void playTrack(int track) {
  if (!playerReady) return;
  // Discard any stale messages, e.g. the "finished" event of a previous
  // prompt that arrived while waiting for SW1 (some modules also send it
  // twice). Otherwise waitForPlaybackToFinish() returns on the old event at
  // once, and the caller may cut power before this track is heard.
  while (player.available()) {
    player.readType();
  }
  player.playMp3Folder(track);
  waitForPlaybackToFinish();
}

bool buttonHeld() {
  return digitalRead(WAKE_BUTTON_PIN) == LOW;
}

void goToSleep() {
  Serial.println("Going to sleep.");
  Serial.flush();
  digitalWrite(SENSOR_MOSFET_PIN, MOSFET_OFF);
  digitalWrite(PLAYER_MOSFET_PIN, MOSFET_OFF);
  // ext0 is level-triggered, so sleeping with SW1 still held would wake
  // straight back up and re-run the cycle. Wait for release first.
  while (buttonHeld()) {}
  delay(DEBOUNCE_MS);
  esp_sleep_enable_ext0_wakeup((gpio_num_t)WAKE_BUTTON_PIN, 0); // wake on LOW
  // SW1 has no external pull-up, and pinMode()'s INPUT_PULLUP doesn't apply
  // once the pin is handed to the RTC domain for ext0. Without this the pin
  // floats in deep sleep, reads LOW, and wakes the MCU immediately.
  rtc_gpio_pullup_en((gpio_num_t)WAKE_BUTTON_PIN);
  rtc_gpio_pulldown_dis((gpio_num_t)WAKE_BUTTON_PIN);
  esp_deep_sleep_start();
}

// Waits for a full press-and-release of SW1. Returns false on timeout.
bool waitForButtonPress(unsigned long timeoutMs) {
  unsigned long start = millis();
  while (!buttonHeld()) {
    if (millis() - start > timeoutMs) return false;
  }
  delay(DEBOUNCE_MS);
  while (buttonHeld()) {}
  delay(DEBOUNCE_MS);
  return true;
}

// Loads the black and white points saved by the last calibration. Both live
// in NVS because RAM (including the library's black offset) is wiped by deep
// sleep.
void loadCalibration() {
  GY33_Raw black;
  prefs.begin("iwand", true);
  if (prefs.getBytes("black", &black, sizeof(black)) == sizeof(black)) {
    sensor.calibrateBlack(black);
  }
  haveWhitePoint = prefs.getBytes("white", &whitePoint, sizeof(whitePoint)) == sizeof(whitePoint);
  prefs.end();
}

void saveCalibrationPoint(const char* key, const GY33_Raw& point) {
  prefs.begin("iwand", false);
  prefs.putBytes(key, &point, sizeof(point));
  prefs.end();
}

// Interactive calibration, entered by holding SW1 at power-up. Expects the
// sensor and DFPlayer to already be started. Each step plays a spoken prompt,
// then waits for a press of SW1 with the wand aimed at the target.
void runCalibration() {
  Serial.println("Calibration mode. Release SW1.");
  while (buttonHeld()) {}
  delay(DEBOUNCE_MS);

  Serial.println("Aim at a WHITE target and press SW1.");
  playTrack(TRACK_CAL_WHITE);
  if (!waitForButtonPress(CAL_STEP_TIMEOUT_MS)) {
    Serial.println("Calibration timed out.");
    return;
  }
  if (!refreshSensor()) {
    Serial.println("Sensor read failed; white point not set.");
    return;
  }
  GY33_Raw white = sensor.getRaw(); // our own white point, used by classifyColour()
  saveCalibrationPoint("white", white);
  // Also calibrate the module's own white balance (affects its processed RGB).
  sensor.calibrateWhiteBalance();
  delay(CAL_SETTLE_MS);
  sensor.saveToFlash(); // keep it across the MOSFET power cuts
  Serial.printf("White point set: r=%u g=%u b=%u c=%u\n", white.r, white.g, white.b, white.c);

  Serial.println("Aim at a BLACK target and press SW1.");
  playTrack(TRACK_CAL_BLACK);
  if (!waitForButtonPress(CAL_STEP_TIMEOUT_MS)) {
    Serial.println("Calibration timed out.");
    return;
  }
  if (!refreshSensor()) {
    Serial.println("Sensor read failed; black point not set.");
    return;
  }
  GY33_Raw black = sensor.calibrateBlack(); // captures the current raw reading
  saveCalibrationPoint("black", black);
  Serial.printf("Black point set: r=%u g=%u b=%u c=%u\n", black.r, black.g, black.b, black.c);

  Serial.println("Calibration complete.");
  playTrack(TRACK_CAL_DONE);
}

void setup() {
  Serial.begin(115200);
  unsigned long serialStart = millis();
  while (!Serial && millis() - serialStart < SERIAL_WAIT_MS) {}
  // Distinguishes a normal button wake from a crash/brownout reset loop.
  Serial.printf("Boot: reset reason %d, wakeup cause %d\n",
                (int)esp_reset_reason(), (int)esp_sleep_get_wakeup_cause());

  pinMode(SENSOR_MOSFET_PIN, OUTPUT);
  pinMode(PLAYER_MOSFET_PIN, OUTPUT);
  digitalWrite(SENSOR_MOSFET_PIN, MOSFET_OFF);
  digitalWrite(PLAYER_MOSFET_PIN, MOSFET_OFF);

  pinMode(WAKE_BUTTON_PIN, INPUT_PULLUP);

  // SW1 is also the wake button, so it's always pressed on a deep-sleep wake.
  // Only treat it as a calibration request on a cold power-up.
  bool coldBoot = esp_sleep_get_wakeup_cause() != ESP_SLEEP_WAKEUP_EXT0;
  if (coldBoot && buttonHeld()) {
    startSensor();
    startPlayer();
    runCalibration();
    stopPlayer();
    stopSensor();
    goToSleep();
  }

  // --- Power the sensor, take one reading, power it back down ---
  startSensor();
  loadCalibration();
  const char* detected = readColour();
  stopSensor();

  Serial.print("Detected colour: ");
  Serial.println(detected);

  // --- Power the DFPlayer, announce the colour, power it back down ---
  int track = trackForColour(detected);
  if (track > 0) {
    startPlayer();
    playTrack(track);
    stopPlayer();
  }

  goToSleep();
}

void loop() {
  // Unused: deep sleep resets the MCU on wake, so execution always restarts
  // from setup() rather than resuming loop().
}

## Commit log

2026-09-24 Initial commit: iWand firmware, electrical schematic, and mechanical notes
    Firmware is an ESP32-S3 (XIAO) sketch that wakes from deep sleep on a
    button press, reads color via a GY-33 sensor over I2C, announces it
    through a DFPlayer Mini + speaker, and sleeps again, with AO3400
    MOSFETs gating power to the sensor and player to conserve battery.
    The electrical/ KiCad schematic is the source of truth for pin
    assignments; mechanical/ has enclosure-relevant context but no design
    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
    [iwand.kicad_sch]
2026-09-24 Regroup wake button and DFPlayer MOSFET pins for tidiness
    Swaps WAKE_BUTTON_PIN (D1->D3) and PLAYER_MOSFET_PIN (D3->D1) so the
    two MOSFET gates sit on adjacent pins (D0/D1) with the button on D3,
    matching the existing D4/D5 (I2C) and D8/D9 (UART) groupings. Sensor
    MOSFET stays on D0. Schematic net labels updated to match (D1/D3_BTN
    swapped between U1's D1 and D3 pins).
    [iwand.kicad_sch]
2026-09-25 Add sensor calibration, switch GY-33 to UART, fix wake loop
    - Calibration mode: hold SW1 at cold power-up, then press SW1 on a white
    and a black target. The white and black points are saved to NVS; the
    module's own white balance is also run and saved to its flash.
    - Classify colours in firmware from raw RGB: normalise to the calibrated
    black/white points, gamma-encode to match perceived brightness, then
    pick Black/White/Gray or a hue band. The library's colour() misreads
    the GY-33's colour byte (bit flags, not an index).
    - Drive the GY-33 over UART (its factory default) on D8/D9; it never
    answered over I2C.
    - Swap buses between D4/D5 (now DFPlayer UART) and D8/D9 (now GY-33),
    i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
    [iwand.kicad_sch]
2026-09-25 Add spoken calibration prompts and play clips by file name
    - Calibration powers the DFPlayer and plays /mp3/0011 (aim at white),
    0012 (aim at black) and 0013 (complete) at each step.
    - Play all clips with playMp3Folder(), which selects by file name rather
    than SD copy order. This removes the need for the track + 1 offset.
    - Drain stale DFPlayer events before each play. A previous prompt's
    finished event made the wait return at once, so the final prompt
    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
2026-09-26 Add SD card audio clips and ignore local build/editor files
    - audio/mp3/0001-0013.mp3: the clips copied to the DFPlayer SD card's
    /mp3 folder (colour names plus the calibration prompts).
    - Ignore the Arduino build output, .vscode (machine-specific paths and
    COM port) and KiCad's per-user .kicad_prl.
2026-09-26 Ignore .build, the renamed Arduino build output folder
2026-09-26 Add PCB footprints and connector-based schematic for board layout
    - New project footprint library electrical/iwand.pretty (via fp-lib-table):
    XIAO ESP32S3 and DFPlayer Mini on female header sockets, and the AO3400
    on its SOT-23 adapter board with pads in the adapter's S-D-G order.
    - Module symbols now have all header pins (XIAO 14, DFPlayer 16), with
    unused pins marked no-connect.
    - Off-board parts become JST-PH side-entry connectors: J1 GY-33
    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
    [iwand.kicad_sch]
2026-09-26 Lay out spine PCB; add power switch and battery monitor
    - New 75.9 x 22 mm board (iwand.kicad_pcb). Parts run along the wand:
    rear JST plugs (battery, speaker, button), XIAO with USB-C over a long
    edge, MOSFET adapters, DFPlayer, then the GY-33 plug facing forward.
    - R1-R6 lie flat under the XIAO. Its courtyard now covers only the
    socket strips and the USB plug, since the module sits ~7.5 mm up in
    low-profile sockets.
    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
    [iwand.kicad_pcb, iwand.kicad_sch]
2026-09-26 Add XIAO ESP32S3 3D model to its footprint
    Seeed's STEP model (electrical/3dmodels, referenced via ${KIPRJMOD}) is
    placed with the offset and rotation from Seeed's own footprint, and
    raised 7.5 mm to where the module sits in its low-profile sockets.
    [XIAO-ESP32S3.step, iwand.kicad_pcb]
2026-09-26 Match 3M low-profile sockets, add DFPlayer 3D model, note wand layout
    - Sockets are 3M 929870 low-profile strips, 3.8 mm tall (from 3M's STEP
    model). The 3D view scales KiCad's 1x7/1x8 socket models to that
    height, and the XIAO model now sits 6.3 mm up.
    - Add DFRobot's DFR0299 STEP model to the DFPlayer footprint (inches,
    Y-up; rotated -90 X / -90 Z so pin 1 matches), with its pin spacer
    resting on the socket top.
    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
    [DFPlayer_Mini.step, iwand.kicad_pcb]
2026-09-27 Route the PCB and add fabrication outputs
    - Route every net on 2 layers: 0.25 mm signals, and 0.5 mm for the Power
    net class (VBAT, BAT_IN, GND, speaker and the switched grounds).
    Branches to R5/R6/C1 and the gate resistors stay 0.25 mm.
    - Shrink module socket pads to 1.6 mm, so a 0.25 mm track can pass
    between two 2.54 mm-pitch pins.
    - GND pours on both layers with 47 stitching vias; min resolved thermal
    spokes set to 1.
    - Tidy the silkscreen: part references inside their outlines, function
    labels, board name and URL on the underside.
    - DRC with schematic parity: 0 violations, 0 unconnected pads.
    - Add fab/iwand-gerbers.zip (Gerbers + Excellon drill) and document the
    routing and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
    [iwand-B_Cu.gbl, iwand-B_Mask.gbs, iwand-B_Silkscreen.gbo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]
2026-09-27 Update root README for the routed PCB
2026-09-28 Export PCB STEP model for Onshape enclosure design
    Add mechanical/iwand-pcb.step, exported from the KiCad board with
    kicad-cli, and document the re-export command, the Onshape import
    steps and what the model leaves out.
    [iwand-pcb.step]
2026-09-28 Add early enclosure prototype exported from Onshape
    [iwand-enclosure.step]
2026-09-28 added bill of materials to electrical folder
    [iwand.csv]
2026-10-07 Split enclosure into top, middle and rear STEP parts
    Replace the single prototype enclosure export with separate Onshape
    exports for each part, and add a STEP model of the 28mm speaker for
    fit checks.
    [28mm 2W 8 Ohm Speaker.step, iWand - Enclosure Middle.step, iWand - Enclosure Rear.step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]
2026-10-08 Update enclosure STEP parts from Onshape
    [iWand - Enclosure Middle.step, iWand - Enclosure Rear.step, iWand - Enclosure Top.step]
2026-10-10 Add 1x04 pin socket STEP models
    [PinSocket_1x04_P2.54mm_Vertical.step, PinSocket_1x04_P2.54mm_Vertical_Stacking.step]
2026-10-13 Update enclosure top and middle STEP parts from Onshape
2026-10-13 Removed 3000 ms wait for serial monitor at boot to save battery.
2026-10-13 Move CLAUDE.md to repo root and bring it up to date
    CLAUDE.md covers the whole product, so it now sits at the root where
    it loads for every session. Describe the current electrical, mechanical
    and audio contents, trim pin-swap history, record the confirmed
    low-side MOSFET wiring and GY-33 UART pinout, and note the Arduino IDE
    build and SERIAL_WAIT_MS. Update README links, fix the firmware README's
    I2C reference, and drop stale comments in firmware.ino.
2026-10-14 Board v0.3: visible J4 polarity marks, JST-PH socket for J5
    J4's +/- silkscreen marks sat under the JST housing, so a reversed
    battery plug went unnoticed. Move the front marks clear of the housing,
    add matching marks on the back beside BAT, and note in the README that
    J4 is the reverse of most LiPo plugs.
    Replace the J5 pin header (XIAO BAT+/BAT- link) with a JST PH top-entry
    socket (B2B-PH-K). It is lower than a header and Dupont plug and takes
    the same PHR-2 plug as J1-J4. A side-entry S2B-PH-K doesn't fit between
    Q2 and SW2. Re-route the nearby GND and VBAT tracks to the new pads.
    Bump the revision to v0.3 and regenerate the Gerbers, drill files and
    the populated PCB STEP model.
    Co-Au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
2026-10-15 Speak battery warnings from the VBAT_SENSE reading
    Read the battery voltage on D10 at each wake, before anything is powered.
    Below BATTERY_LOW_MV (3500) play 0014.mp3 after the colour name; below
    BATTERY_CRITICAL_MV (3300) play 0015.mp3 and sleep without reading.
    Thresholds are starting guesses to check against a multimeter.

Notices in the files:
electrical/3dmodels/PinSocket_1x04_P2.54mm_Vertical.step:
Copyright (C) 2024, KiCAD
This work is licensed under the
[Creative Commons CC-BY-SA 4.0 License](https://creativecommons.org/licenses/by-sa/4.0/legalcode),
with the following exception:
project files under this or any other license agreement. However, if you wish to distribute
